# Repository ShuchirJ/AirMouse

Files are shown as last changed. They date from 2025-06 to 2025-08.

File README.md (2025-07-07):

# The Wand
A fun little mouse that doesn't need an optical sensor! The wand has two physical buttons to act as left and right mouse buttons. A gyroscope acts as a scroll controller, scrolling up and down based on the tilt of the wand. An accelerometer detects the movement of the wand, allowing it to be used as a mouse pointer. An ESP32S3 powers the wand, and it connects to a computer via Bluetooth HID.

### Why?
Two main reasons:
1. I teach codding and math classes every week, and I'd love to write on a digital whiteboard. Unfortunately, I find drawing with my current mouse hard. I think the Wand is smaller, so it should be nicer to hold (it's like a very very chunky pencil). I think it would also be cool to be able to draw in midair so I can write on the whiteboard while walking around the classroom.
2. I work on a very glossy table sometimes and my optical mouse doesn't work well on it. The Wandd should solve this problem, since it's based on motion only.

## 3D Model
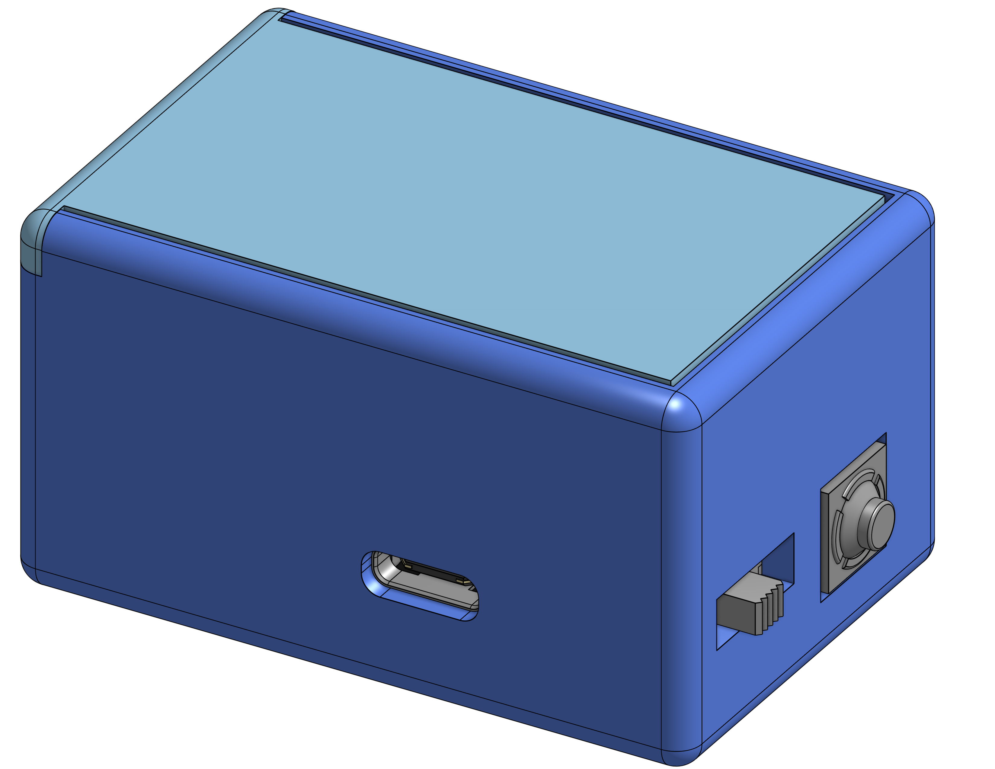
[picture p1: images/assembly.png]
assembly
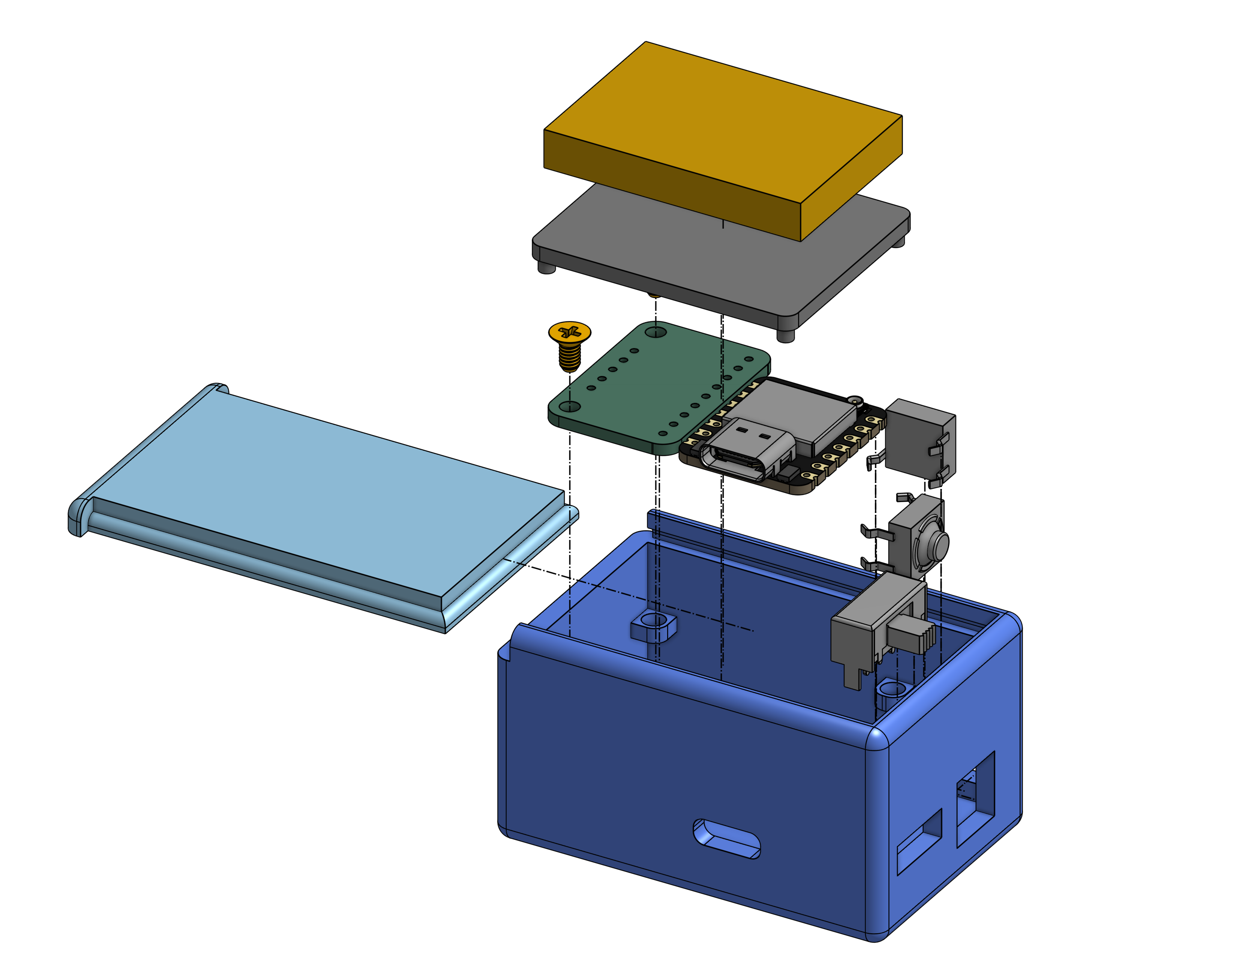
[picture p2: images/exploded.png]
exploded
 

## Wiring
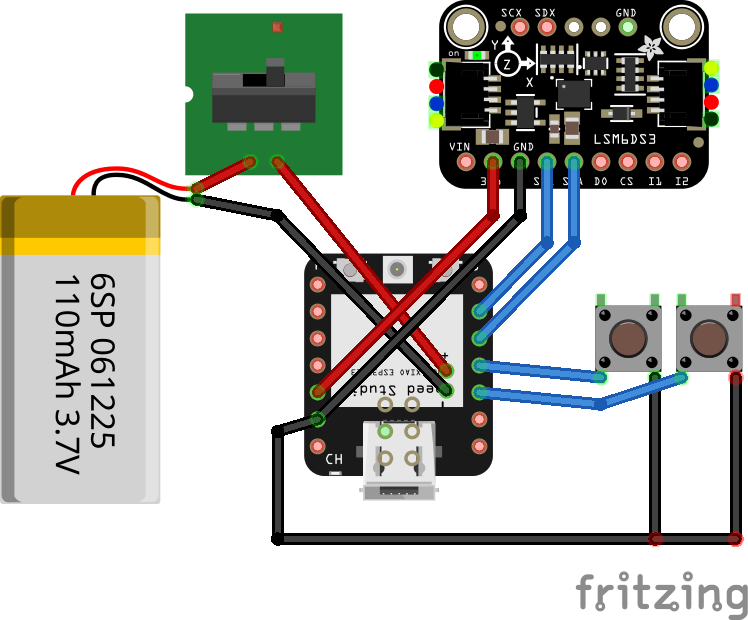
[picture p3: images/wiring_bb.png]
wiring


*Note: Despite what the wiring diagram says, the Wand plans to use a 420mAh battery*

## BOM
See the bom [here](BOM.csv) too!
| Part | Quantity | Price (USD) | Source |
| ---- | --- | --- | --- |
| Xiao ESP32S3 | 1 | 7.49 | [Seeed](https://octopart.com/opatz8j6/a1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) |
| Adafruit LSM6DSOX 6 DoF Accelerometer and Gyroscope | 1 | 11.95 | [Adafruit](https://www.adafruit.com/product/4438) |
| Soft Tactile Buttons (Pack of 10) | 1 | 1.95 | [Adafruit](https://www.adafruit.com/product/3101) |
| 420mAh LiPo Battery | 1 | 6.95 | [Adafruit](https://www.adafruit.com/product/4236) |
| JST Header | 1 | 0.75 | [Adafruit](https://www.adafruit.com/product/3814) |
| 24 AWG Silicone Wire (1 ft) | 3 | 2.85 | [Mouser](https://octopart.com/opatz8j6/a1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) |
| M2.5x.45 Thread Screws | 2 | 0.22 | [Mouser](https://octopart.com/opatz8j6/a1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) |
| Slide switch | 1 | 0.35 | [Mouser](https://octopart.com/opatz8j6/a1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) |
| Wire stripper/cutter | 1 | 6.99 | [Amazon](https://a.co/d/gpYgt5D) |
| LiPo Safe Battery Pouch | 1 | 12.99 | [Amazon](https://a.co/d/eOVSK29) |

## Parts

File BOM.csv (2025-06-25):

Matched Part Number | Matched Manufacturer | Description | Selected Offers | Selected Offers (Distributor Link) | Unit Price | Total Quantity | Total Price
113991114 | Seeed Studio | Development Board, 32 Bit, Xtensa LX7; | Mouser 713-113991114 | https://octopart.com/opatz8j6/a1 | 7.49 | 1 | 7.49
4438 | Adafruit Industries | Adafruit Lsm6Dsox 6 Dof Accelerometer And Gyroscope - Stemma Qt/Qwiic |Adafruit 4438 | Mouser 485-4438 | https://octopart.com/opatz8j6/a1 | 11.95 | 1 | 11.95
3101 | Adafruit Industries | Product Type = Button / Length mm = 7.8 / Width mm = 7.8 / Height mm = 4.9 / Weight mg = 100 | Mouser 485-3101 | https://octopart.com/opatz8j6/a1 | 1.95 | 1 | 1.95
4236 | Adafruit Industries | Lithium Ion Polymer Battery with Short Cable - 3.7V 420mAh | Adafruit Industries 4236 | Mouser 485-4236 | https://octopart.com/opatz8j6/a1 | 6.95 | 1 | 6.95
3814 | Adafruit Industries | JST PH 2-Pin Cable Male Header 200mm | Adafruit Industries 3814 | Mouser 485-3814 | https://octopart.com/opatz8j6/a1 | 0.75 | 1 | 0.75
99M0111-24-9 | TE Connectivity / Raychem | Hook-Up Wire, Type99(R) Primary Wire White 24 AWG | TE Connectivity 99M0111-24-9 | Mouser 650-99M0111-24-9 | https://octopart.com/opatz8j6/a1 | 0.95 | 3 | 2.85
50M025045I005 | Essentra | Screws & Fasteners 90 Phillips CSK Screw, M2.5 X .45 Thread, 5mm Lg, Flat, Natural, Nylon | Mouser 144-50M025045I005 | https://octopart.com/opatz8j6/a1 | 0.11 | 2 | 0.22
SLW-1298856-5A-RA-N-D | Same Sky | Switch Slide ON ON SPDT Raised Slide 0.3A 50VDC 10000Cycles PC Pins Thru-Hole | Mouser 179-SLW12988565ARAND | https://octopart.com/opatz8j6/a1 | 0.35 | 1 | 0.35
7 in/ 22-30 AWG | Dowell | DOWELL 22-30 AWG Wire Stripper Wire Stripping Tool Wire Cutter And Multi-Function Hand Tool | Amazon | https://a.co/d/gpYgt5D | 6.99 | 1 | 6.99
889551102049 | Emate | OVONIC Lipo Safe Bag Fireproof Explosionproof Bag Large Capacity Lipo Battery Storage Guard Safe Pouch for Charge & Storage | Amazon | https://a.co/d/eOVSK29 | 12.99 | 1 | 12.99

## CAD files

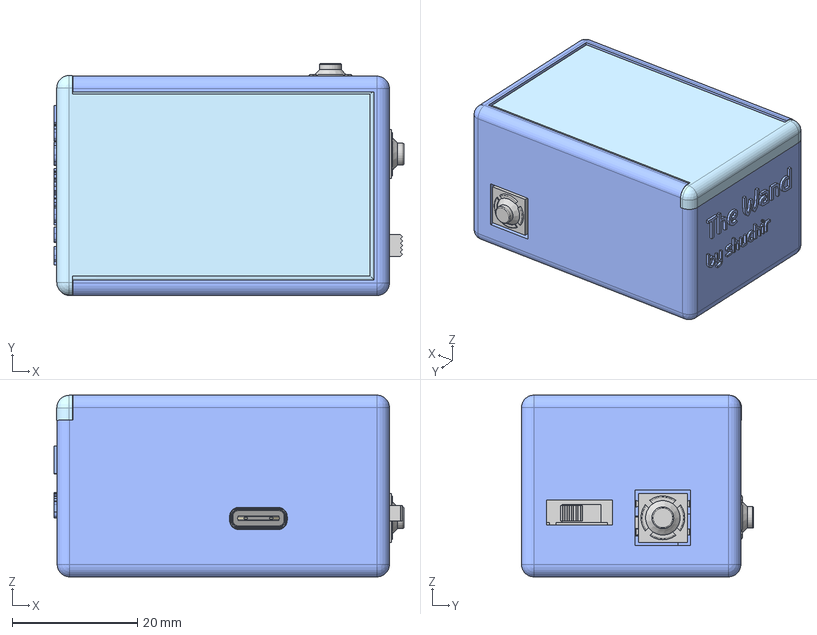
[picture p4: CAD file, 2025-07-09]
3D/assembly.step
55.8 x 37.0 x 29.0 mm
8mm soft button v1 x 10
BOSS-EXTRUDE7_7_
BOSS-EXTRUDE7_6_
BOSS-EXTRUDE7_5_
Pins_1 x 4
BOSS-EXTRUDE14_7_
lid
BOSS-EXTRUDE7_2_
U.FL-R-SMT-1_10_ v1
BOSS-EXTRUDE14_5_
BOSS-EXTRUDE14_11_
BOSS-EXTRUDE14_8_
BOSS-EXTRUDE14_9_
screw x 2
battery plate
BOSS-EXTRUDE14_1_
BOSS-EXTRUDE14_2_
case
BOSS-EXTRUDE14_10_
BOSS-EXTRUDE14_12_
BOSS-EXTRUDE7_4_
Pins x 4
Same_Sky_SLW-1298856-5A-RA-N-D
BOSS-EXTRUDE7_8_
BOSS-EXTRUDE7_3_
BOSS-EXTRUDE14_4_
BOSS-EXTRUDE7_1_
Seeed Studio XIAO-ESP32-S3 (Sense)
BOSS-EXTRUDE14_3_
BOSS-EXTRUDE14_6_
CUT-EXTRUDE5
Adafruit_LSM6DSOX_PCB
Shield
BOSS-EXTRUDE7_9_
MIRROR2

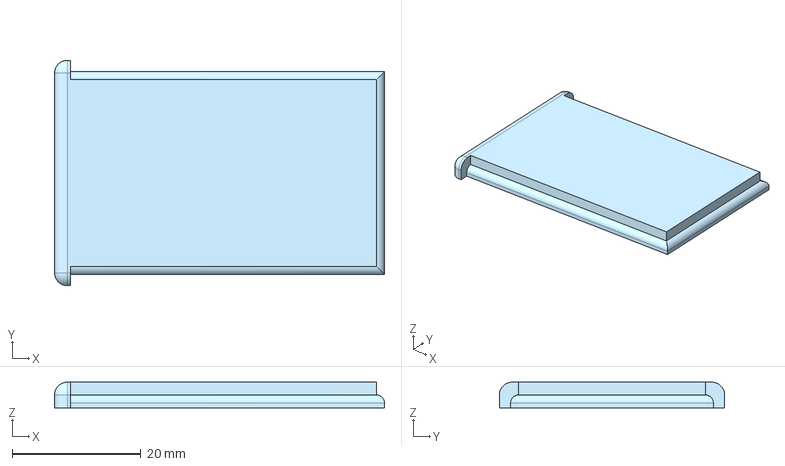
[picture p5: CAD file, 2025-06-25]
3D/lid.step
51.2 x 35.0 x 4.00 mm

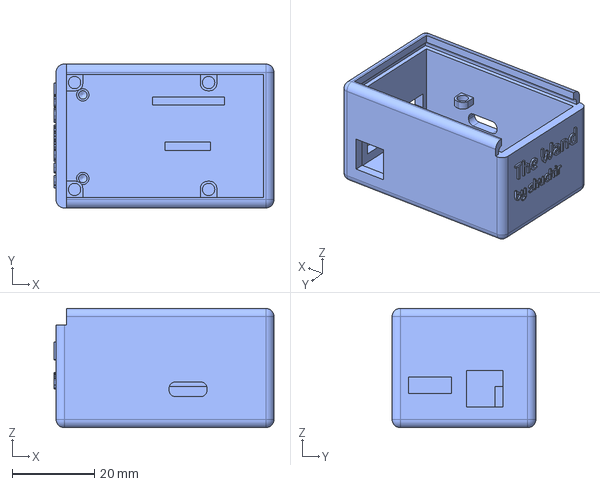
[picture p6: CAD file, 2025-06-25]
3D/case.step
53.5 x 35.0 x 29.0 mm

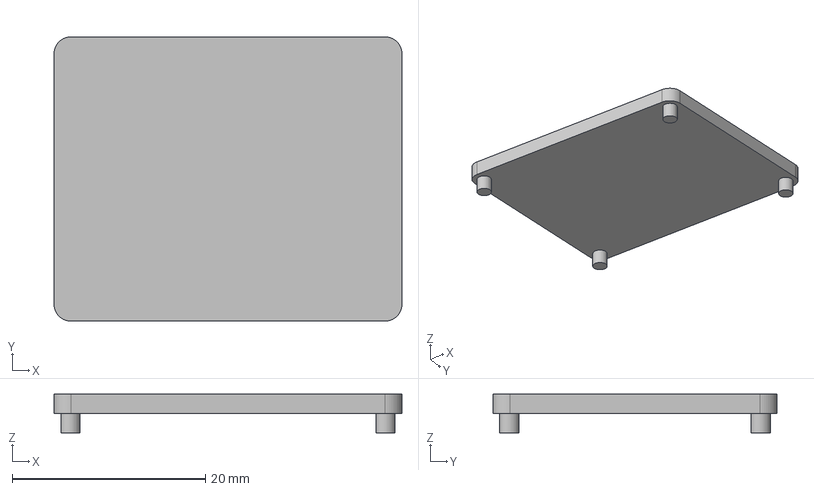
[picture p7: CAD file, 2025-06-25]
3D/battery plate.step
36.0 x 29.4 x 4.00 mm

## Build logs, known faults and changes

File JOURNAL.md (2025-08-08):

---
title: "The Wand"
author: "shuchir"
description: "Wave the wand and see magic appear on your screen!"
created_at: "2025-05-26"
---

Total time taken: 11 hr 40 min

## 5-26 00:00: Planning
It's planning day today! I want to research a litle and figure out the best way to do things. The design: have a mouse controlled entirely by accelerometers and gyroscopes. I'm aware it's worse than an optical mouse this way, but I would really like a way to write on something like excalidraw as if i was writing with an normal pen- so the mouse should be small enough to fit in my palm. 
The 3 main things that come to my mind today: the MCU, accelerometer/gyroscope, and battery. MCU should ideally support BLE because it's way nicer than having a wire coming out your palm (also my goal is to use this on a projector so I'd need a really long wire). 

Small MCUs: the XIAO ESP32C3 (supports BLE!!), Tiny 2350, teensy (too big for my palm), QT Py

The xiao esp32c3 also has battery charging support so that's what I'm leaning towards.

For battery: again need something small; maybe [this](https://www.adafruit.com/product/1578)? it has decent charge for probably a few hours, and it's a small 3.5 x 3.5 cm square ish bat.

accelerometer + gyroscope: [this](https://www.adafruit.com/product/4503) looks cheap and good enough for what I need!

**Time taken: 20 min**

## 5-27 19:00: Wiring
Took a look at how everything should go together and came up with this wiring diagram:



seems fairly simple??

**Time taken: 15 min**

## 5-27 21:00: I forgot the buttons.
I don't want to use the buttons onboard the esp because I want to position them along the outside of the mouse, so they'll need to be a little flexible. Now I'm not 100% confident but I think [the ESP should have internal pull ups](https://www.espressif.com/sites/default/files/documentation/esp32-c3_datasheet_en.pdf), so I wont need resistors. 4 wires going to a single ground pin makes me a little uneasy though. Tomorrow I'll start designing the case, and hopefully in a few days I'll have written the code and finish the case.

the_wand_wiring

**Time taken: 15 min**

## 5-28 09:00: Code
Decided to do the code first; Started simulating on wokwi: https://wokwi.com/projects/432109492341468161

Got the accelerator/gyroscope working and printing actual values, but I just realized the ESP32C3 doesn't support HID- stay tuned !!

**Time taken: 30min**

## 5-28 18:00: Code Part 2
Did a little more research and it seems like the ESP32S3 is really similar and does support HID- so that's what I'll be using instead. Replaced the MCU on wokwi. Noticed one thing though: the MPU6050 (similar to what I plan to use: the ST LSM6DS3TR-C) doesn't let you "zero" the sensor to a new position; I think it'll be more worthwhile to remove the calibrate button then. Removing the calibrate button, and adding a power switch because I forgot that the first time around;


Back to the code; I think I can use https://github.com/T-vK/ESP32-BLE-Mouse to act as the BLE mouse controller

wokwi needs you to pay to upload a library...we're going to continue blind then 🤩
I'll do as much as I can before adding mouse support then add that later.

Added some basic logic to handle angles, and added skeleton logic for mouse events!

**Time taken: 1 hour**

## 5-29 18:30: Code part 3
Okay I was approaching my code wrong- I was trying to take absolute positional degree/x/y/z movements, finding their speeds, then reapplying that to the mouse movement. ??? I realized I can pass the accel/gyro speeds to the mouse directly, so I rewrote the code to do that. Also realized I was moving mouse on gyro movementsi instead of accel. movements, so I fixed that by making the gyro the scroll and the accel. the mouse movements. I think that's pretty much done, I need to implement button presses now but that should be very simple- just reading the value of a button and calling mouse.press when it happens.

**Time taken: 30 min**

## 6-7 7:30 PM: Finishing the code, BOM
Finished the code! I added the button presses, and now it works as a mouse. Before I start designing the case, I need to figure out the BOM so I know what parts to design for. I know I'll be using the XIAO ESP32S3 and [this](https://www.adafruit.com/product/4237) battery, I just need to finalize the accelerometer/gyroscope and the exact buttons now. For the accelerometer i think I was thinking of something before, but I'll go with [LSM6DSOX](https://www.adafruit.com/product/4438) because it seems like it has very low noise - lower than the MPU6050. The code will change a little; Let me change that now

Ok, done and uploaded- [mouse.ino](mouse.ino)

BOM time!! these [soft buttons](https://www.adafruit.com/product/3101) look nice, and I'll go with a typical [rocker switch](https://www.robotshop.com/products/sfe-on-off-rocker-switch?gQT=1) for the power. That should be all!

BOM: [BOM.csv](BOM.csv)

while thinking of this ive now run into another problem: i need a 3 way splitter for the ground pin on the esp, but i can't find any

it's fine i'll just strip the wires and solder them together and make my own splitter

summary for today: writing more code, part sourcing, thinking 🥺
**Time taken: 2 hrs**

## 6-11 9:30 PM: More part sourcing, Start CAD
Ok, I did some more part sourcing to buy more things from mouser so its cheaper. I've added screws and wires to the BOM, I'll upload it soon. I think the only thing left is the elastic band i wanted to add. I've also started cadding:

The design thought here is this:

3 layers; bottom is accelerometer screwed in for accuracy, and the two left/right buttons accessible from the bottom (easier to click while holding in the hand i think). Middle layer is the ESP; one of the walls will have a cutout for the XIAO's USB port so I can charge the device without needing to open the whole thing up. Third and final layer will be the battery. Still not sure how I'm going to design the lid, because I want it to be ome sort of snapfit so it's easy to open but I also don't really know how to design snap fits so uhh we'll see I guess. One of the walls will also have a cutout for the power switch. 

**Time Taken: 1.5 hrs**

## 6-12 8:45 PM: CAD
I've started dropping the cad models for my actual components in so I can design around them. So far, I've rethought where Iw ant the buttons to be. I also think 3 layers will be too thick, so I'll sacrifice an extra 5mm width for a thinner device. The XIAO is laying next to the accelerometer, but I'm not sure how to secure it in especially since there are no mounting holes. here's where I'm at now:


Thought about it for a quick second and I'll put small walls around the xiao so it doesn't move hopefully that's enough 😭 I'm thinking of putting a screwable panel on top of both the boards anyways to separate the battery, so maybe that'll all hold the ESP in. Made a cutout for the usb port, and stuck my button in.
 

what's left: the other button, tolerances for the buttons, power switch, separation panel (?), battery (?), and lid. I think lid will be the hardest considering I have like no experience but we'll see. 

**Time taken: 2.5 hrs**

## 6-13 11:00 PM: Rocker Switch
Spent a few min adding a cutout for the rocker switch...how in the world is it so big

I need to rethink this, potentially findding a smaller rocker switch because this leaves like no space for the battery.

**Time taken: 20 min**

## 6-22 10:00 PM: Slideswitches
Okay back after a hiatus. looked into slideswitches instead of rockers; I think they'll work, but it's not worth it to have the rocker switch on this existing model. I want to extend the model a little bit, open it up a little, then make some space for the switch on the side.

mini update: I got the switch in, but I think my second button (for right clicking, etc.) might be too close


also just realizing the holes arent big enough for the buttons; i think i should be able to push the prongs in? I'm not sure whether thsi much interference warrants me opening the hole a little 



I've adjusted the spacing there, I'm more comfortable with the gap now. If it still doesn't work out, I can bend the pins a little or push the buttons out further.

To do: add a little flat plate for the battery to sit on, check the battery in the case, add lid, clean up the case.

**Time taken: 1hr**

## 6-23 11:00 AM: Battery
Preliminary battery fitting:



I mean it fits alright, but the lead wires are an additional 25mm. The edge of the battery to the edge of the case is 12 mm. I'm thinking I'll loop the wire above the battery (so just let it sit on top of the battery) so it'll probably be okay? There seems to be enough space to maneuver the wires without crimping them. I'm afraid I'm not giving myself enough wiggle room here tho...

battery plate!! 



To clarify, the main reason I want this plate between the battery and the rest of the components is bc I don't want anything to accidentally puncture/affect the battery- I'd like as much separation as possible.

To do: lid, polishes

**Time taken: 45 min**

## 6-24 10:00 AM: Lid + final touches
I've decided on a sliding lid. I just did a sliding lid on another one of my projects and it worked out quite well imo. The only thing is it'll add a little bit of height but it's ok.

made the rails (will filet the inside later):



lid!!!



time to polish

done !!



fileted it a bunch so it's comfortable to hold + added a nice little embossing. 

To do: update BOM, write README, upload CAD source files

**Time taken: 45 min**

Hello! I didn't do any journaling while building unfortunately so I'll leave a few notes:
- playing with the accelerometer took me a week alone. Integration led to a lot of drifting, and getting it to track my hand accurately was a challenge in itself. but I finally got it! Will update the code in mouse.ino when I have time
- The end result is far too bulky and clicking does not seem to work. need to investigate more and think of a better design. It's possible a custom PCB will make it less bulky but I'm not sure there's any worth exploring this right now.

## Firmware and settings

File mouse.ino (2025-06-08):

#include <Adafruit_LSM6DSOX.h>
#include <Adafruit_Sensor.h>
#include <Wire.h>
#include <BleMouse.h>

BleMouse bleMouse("The Wand");
Adafruit_LSM6DSOX sox;
int BUTTON_LEFT = 3;
int BUTTON_RIGHT = 4;

bool prevLeft = false;
bool prevRight = false;

void setup(void) {
  Serial.begin(115200);
  
  pinMode(BUTTON_LEFT, INPUT_PULLUP);
  pinMode(BUTTON_RIGHT, INPUT_PULLUP);

  initalize
  if (!sox.begin_I2C()) {
    Serial.println("Failed to init accel.");
    while (1) {
      delay(10);
    }
  }
  Serial.println("accel. initialized");

  sox.setAccelRange(LSM6DS_ACCEL_RANGE_2_G);
  sox.setGyroRange(LSM6DS_GYRO_RANGE_250_DPS);
  sox.setAccelDataRate(LSM6DS_RATE_104_HZ);
  sox.setGyroDataRate(LSM6DS_RATE_104_HZ);

  bleMouse.begin();
}

void loop() {
  sensors_event_t a, g, temp;
  sox.getEvent(&a, &g, &temp);

  if (bleMouse.isConnected()) {
    sensors_event_t a, g, temp;
    sox.getEvent(&a, &g, &temp);

    int moveX = a.acceleration.x * 2; 
    int moveY = a.acceleration.y * 2; 

    int scroll = g.gyro.y * 2;

    if (abs(moveX) < 1) moveX = 0;
    if (abs(moveY) < 1) moveY = 0;
    if (abs(scroll) < 0.5) scroll = 0;

    if (moveX != 0 || moveY != 0) {
      bleMouse.move(moveX, moveY);
    }

    if (scroll != 0) {
      bleMouse.move(0, 0, scroll);
    }

    bool leftPressed = digitalRead(BUTTON_LEFT) == LOW;
    bool rightPressed = digitalRead(BUTTON_RIGHT) == LOW;

    if (leftPressed && !prevLeft) {
      Serial.println("press left");
      bleMouse.press(MOUSE_LEFT);
      prevLeft = true;
    } else if (!leftPressed && prevLeft) {
      Serial.println("release left");
      bleMouse.release(MOUSE_LEFT);
      prevLeft = false;
    }

    if (rightPressed && !prevRight) {
      Serial.println("press right");
      bleMouse.press(MOUSE_RIGHT);
      prevRight = true;
    } else if (!rightPressed && prevRight) {
      Serial.println("release right");
      bleMouse.release(MOUSE_RIGHT);
      prevRight = false;
    }
  }

  delay(20);
}

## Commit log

2025-06-08 code and bom
    [BOM.csv]
2025-06-25 Update BOM
    [BOM.csv]
2025-06-25 add cad source files
    [battery plate.step, case.step, lid.step]
2025-06-25 add readme, images, wiring diagram
    [wiring.fzz]
2025-07-09 add assembly file
    [assembly.step]
